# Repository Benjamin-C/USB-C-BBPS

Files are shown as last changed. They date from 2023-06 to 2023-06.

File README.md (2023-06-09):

# USBC-BBPS
A USBC-PD powered breadboard power supply with selectable voltage outputs. This lets you power your project with 3.3V and/or a voltage of your choice provided by a USBC Power Delivery capable power supply.

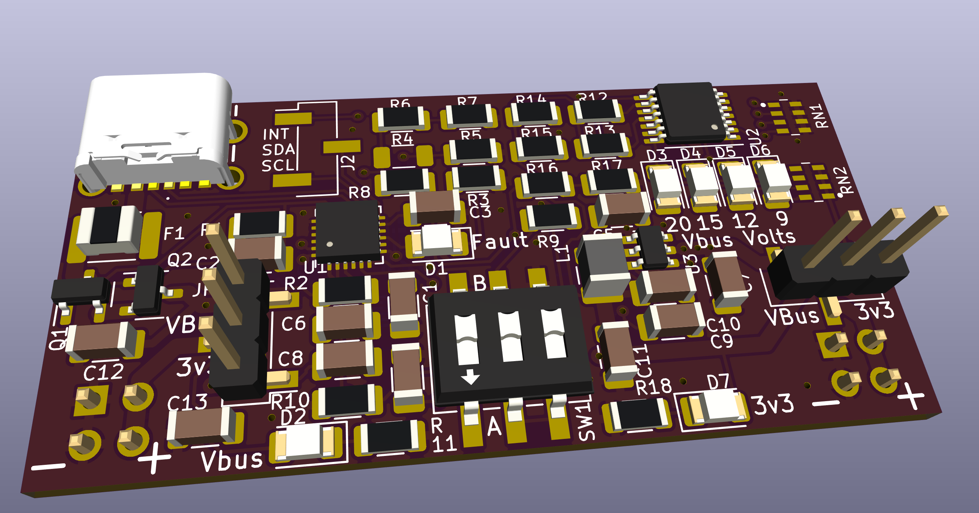
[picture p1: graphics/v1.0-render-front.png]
Front render

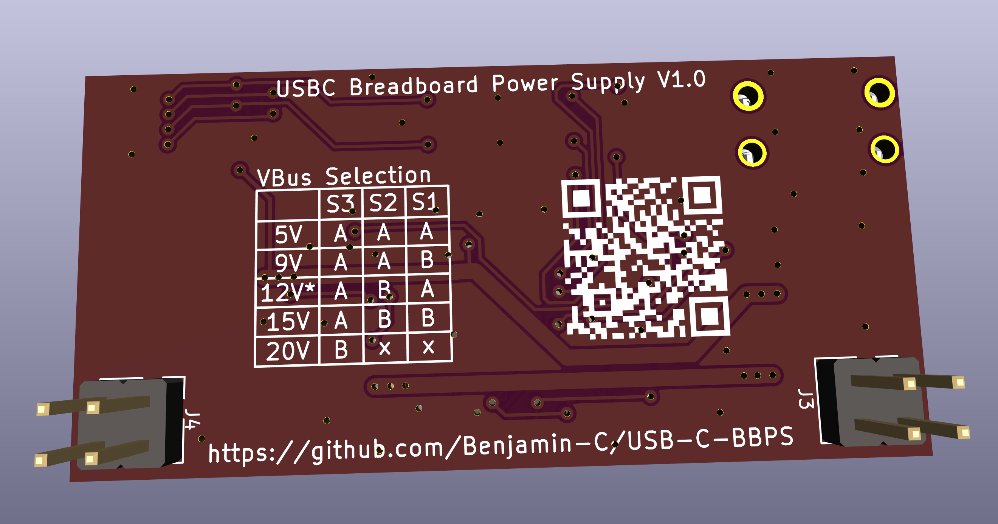
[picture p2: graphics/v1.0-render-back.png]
Front render


## Major Features
* A [CYPD3177-24LQXQT](https://www.infineon.com/cms/en/product/universal-serial-bus/usb-c-charging-port-controllers/ez-pd-barrel-connector-replacement-bcr/cypd3177-24lqxqt/) USBC PD Interface IC to supporting PD3.0 Revision 2.0 Version 1.3
* A [AP63203WU](https://www.mouser.com/ProductDetail/Diodes-Incorporated/AP63203WU-7?qs=u16ybLDytRZ1JqxbuLkMJw%3D%3D) 3.3V switching regulator to always have 3.3V available for microcontrollers
* An [LM339PWRG4](https://www.ti.com/product/LM339/part-details/LM339PWRG4) based voltage monitor
* 2x2 0.1" Pin headers spaced to fit standard solderless breadboards

## Ratings
* VBUS has a 1.5A polyfuse, so no more than 1.5A may be drawn between the VBUS output and 3.3V regulator (noting that the current drawn by the regulator from VBUS will be less than the current drawn on 3.3V).
* Do not feed power back into either 3.3V or VBUS. Doing so may kill the board or possibly the USB power supply
* Each side of the board has a maximum of 1A. This is not regulated on the board, so don't draw more than that.

## Configuration
### VBUS selection:
| | SW3 | SW2 | SW1 |
|---|-----|-----|-----|
| 5V |  A  |  A  |  A  |
| 9V |  A  |  A  |  B  |
| 12V* |  A  |  B  |  A  |
| 15V  |  A  |  B  |  B  |
| 20V  |  B  |  x  |  x  |

\* 12V is an optional part of the USBC-PD spec, so many laptop chargers including most Apple ones do not support 12V.

### Output Voltage Selection
* Use the 3-pin jumpers on each side of the board to select the voltage output to that side of the breadboard.
* Each side can be independently selected to be 3.3V or VBUS.
* Only 1 VBUS voltage may be used at a time, but it may be used on both sides of the board.
* For any voltage over 5V, one or more of the output voltage monitoring LEDs will be lit. The output voltage is the highest value with a lit LED.
* Power will only be provided to the board once USBC-PD negotiations have completed and the desired voltage has been provided.

### Errors
* If the board is not able to negotiate at least the desired voltage from the upstream power supply, the outputs will be turned off and the fault LED will be turned on and power will be cut from the board.
* If the polyfuse is tripped, all lights on the board will turn off. To reset the polyfuse, turn disconnect power from the board, remove the cause of the over current event, and return power to the board.
* If there is a larger over current event, the protection in the USBC power supply may be triggered before the polyfuse reacts. To fix this, disconnect power from the board, remove the source of the nonrecurrent event, then reconnect power to the board.
* If the 3.3V light and voltage monitoring lights are blinking but the VBUS light is on, this is an indication that the 3.3V regulator may be damaged and require replacement.

## Assembly
* Mount the switch so that the switches are "on" when the switch is towards the bottom of the board and "off" when the switch is towards the top of the board. A "A" state is when the switch is down towards the bottom of the board (connected), and a "B" state is when the switch is towards the top of the board (disconnected)
* Be sure to securely solder the mounting tabs on the USBC connector to prevent damage to the board if the cable is pulled.

## More features!
* The 3 pin connector near the USBC connector exposes the I2C lines from the [CYPD3177-24LQXQT](https://www.infineon.com/cms/en/product/universal-serial-bus/usb-c-charging-port-controllers/ez-pd-barrel-connector-replacement-bcr/cypd3177-24lqxqt/) USBC PD Interface IC, and can be connected to a microcontroller for additional features.

## Design notes
This board was designed entirely by me based on the reference schematics for the utilized ICs.

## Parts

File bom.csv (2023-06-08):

USB-C Powered Breadboard Power Supply V1.0
All parts ordered from Mouser
Thu 08 Jun 2023
Component Count: | 56
Item | Qty | Reference(s) | Value | DPN | MPN
1 | 7 | C1, C3, C7, C10, C11, C12, C13 | 10u | 187-CL31A106MBHNNNE | CL31A106MBHNNNE
2 | 5 | C2, C4, C5, C6, C8 | 1u | 187-CL31B105KBHNFNE | CL31B105KBHNFNE
3 | 1 | C9 | 0.1u | 187-CL31B104KBCNNND | CL31B104KBCNNND
4 | 7 | D1, D2, D3, D4, D5, D6, D7 | LED | 710-156120RS75000 | 156120RS75000
5 | 1 | F1 | 2A | 576-1812L150/24MR | 1812L150/24MR
6 | 1 | J1 | USB_C_Receptacle_PowerOnly_6P | 649-10164359-00011LF | 10164359-00011LF
7 | 1 | J2 | DNP | 649-1012938090301ALF | 10129380-903001ALF
8 | 2 | J3, J4 | Conn_02x02 | 649-1012938190403BLF | 10129381-904003BLF
9 | 2 | JP1, JP2 | Jumper_3_Bridged12 | 649-1012938090301ALF | 10129380-903001ALF
10 | 2 | JS1, JS2 | ~ | 855-M7581-05 | M7581-05
11 | 1 | L1 | 4.7u | 652-SRP3212A-4R7M | SRP3212A-4R7M
12 | 2 | Q1, Q2 | Q_PMOS_GSD | 621-DMP3099L-7 | DMP3099L-7
13 | 2 | R1, R17 | 10k | 652-CR1206FX-1002ELF | CR1206-FX-1002ELF
14 | 1 | R2 | 100 | 652-CR1206FX-1000ELF | CR1206-FX-1000ELF
15 | 3 | R3, R7, R18 | 2k2 | 652-CR1206FX-2201ELF | CR1206-FX-2201ELF
16 | 1 | R4 | DNP
17 | 1 | R5 | 0 | 652-CR1206-J/-000ELF | CR1206-J/-000ELF
18 | 3 | R6, R8, R11 | 5k1 | 652-CR1206FX-5101ELF | CR1206FX-5101ELF
19 | 1 | R9 | 3k | 652-CR1206FX-3001ELF | CR1206-FX-3001ELF
20 | 1 | R10 | 1k2 | 652-CR1206FX-1201ELF | CR1206-FX-1201ELF
21 | 1 | R12 | 10.5k | 652-CR1206FX-1052ELF | CR1206FX-1052ELF
22 | 1 | R13 | 49.9k | 652-CR1206FX-4992ELF | CR1206FX-4992ELF
23 | 1 | R14 | 90.9k | 652-CR1206FX-9092ELF | CR1206FX-9092ELF
24 | 1 | R15 | 162k | 652-CR1206FX-1623ELF | CR1206FX-1623ELF
25 | 1 | R16 | 53.6k | 652-CR1206FX-5362ELF | CR1206-FX-5362ELF
26 | 1 | RN1 | 100k | 603-TC164-FR-07100KL | TC164-FR-07100KL
27 | 1 | RN2 | 2k2 | 603-YC164-FR-072K2L | YC164-FR-072K2L
28 | 1 | SW1 | SW_DIP_x03 | 490-DS04254203BK-SMT | DS04-254-2-03BK-SMT
29 | 1 | U1 | CYPD3177 | 727-CYPD3177-24LQXQT | CYPD3177-24LQXQT
30 | 1 | U2 | LM339 | 595-LM339PWRG4 | LM339PWRG4
31 | 1 | U3 | AP63203WU | 621-AP63203WU-7 | AP63203WU-7

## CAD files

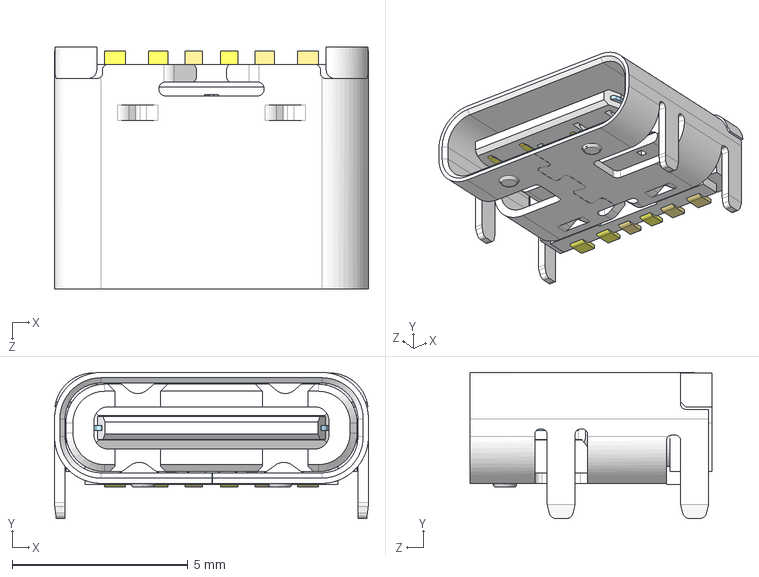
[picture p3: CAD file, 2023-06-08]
3d/J-Amphenol-USB-C.stp
8.94 x 4.16 x 6.90 mm

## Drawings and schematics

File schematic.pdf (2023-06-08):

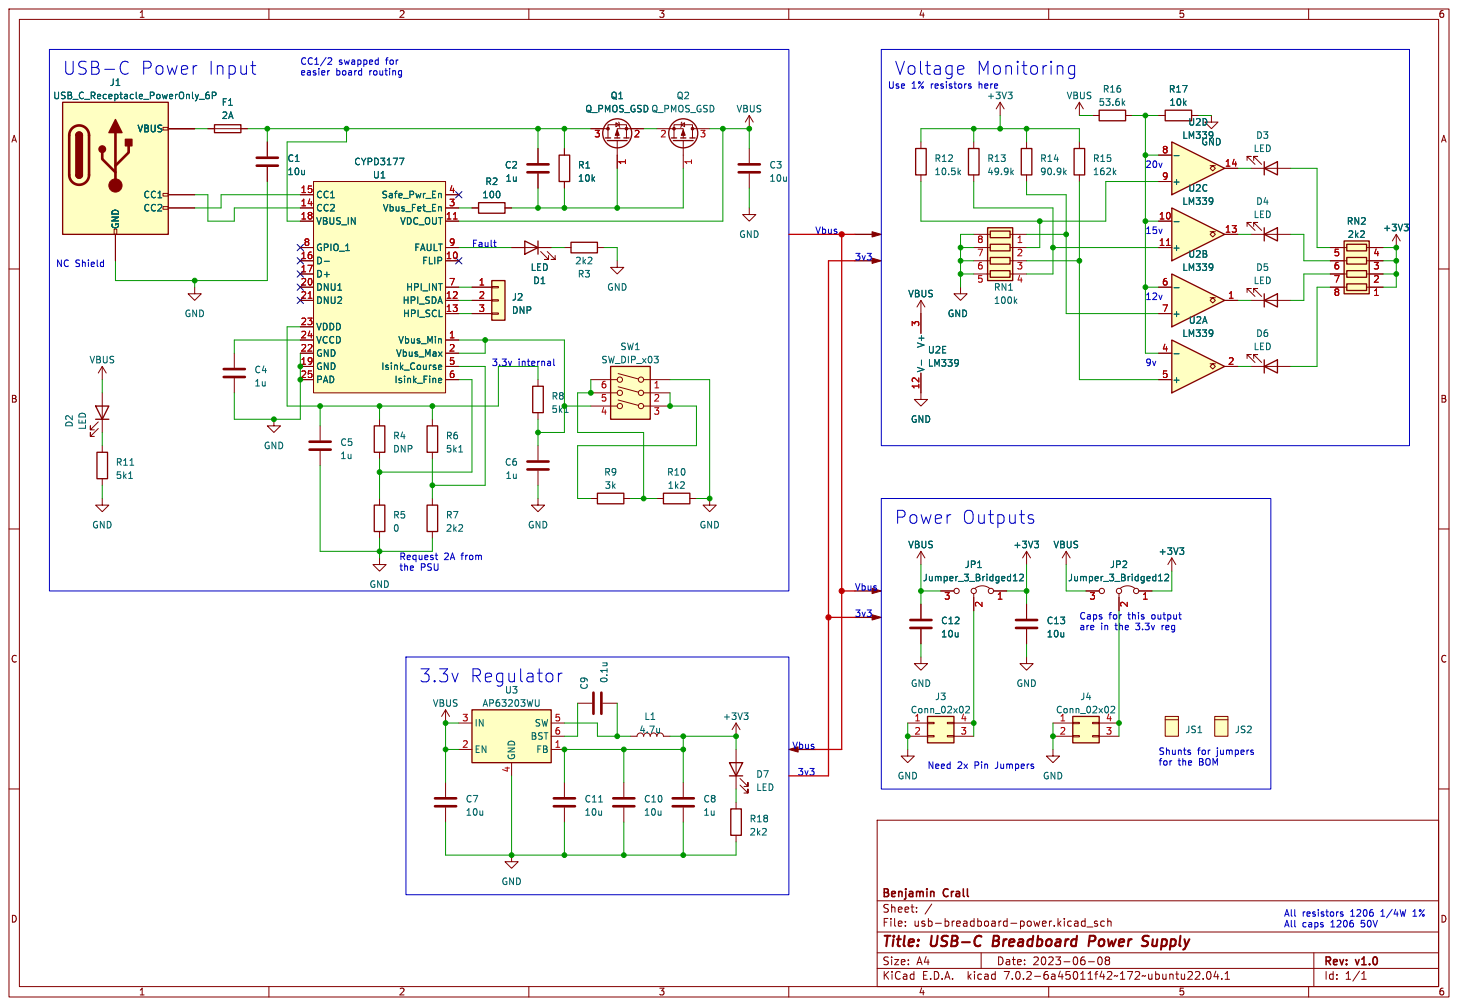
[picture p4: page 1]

All caps 1206 50V Caps for this output are in the 3.3v reg Power Outputs
10u VBUS

File: usb-breadboard-power.kicad_sch Sheet: / Benjamin Crall

Id: 1/1 Title: USB-C Breadboard Power Supply

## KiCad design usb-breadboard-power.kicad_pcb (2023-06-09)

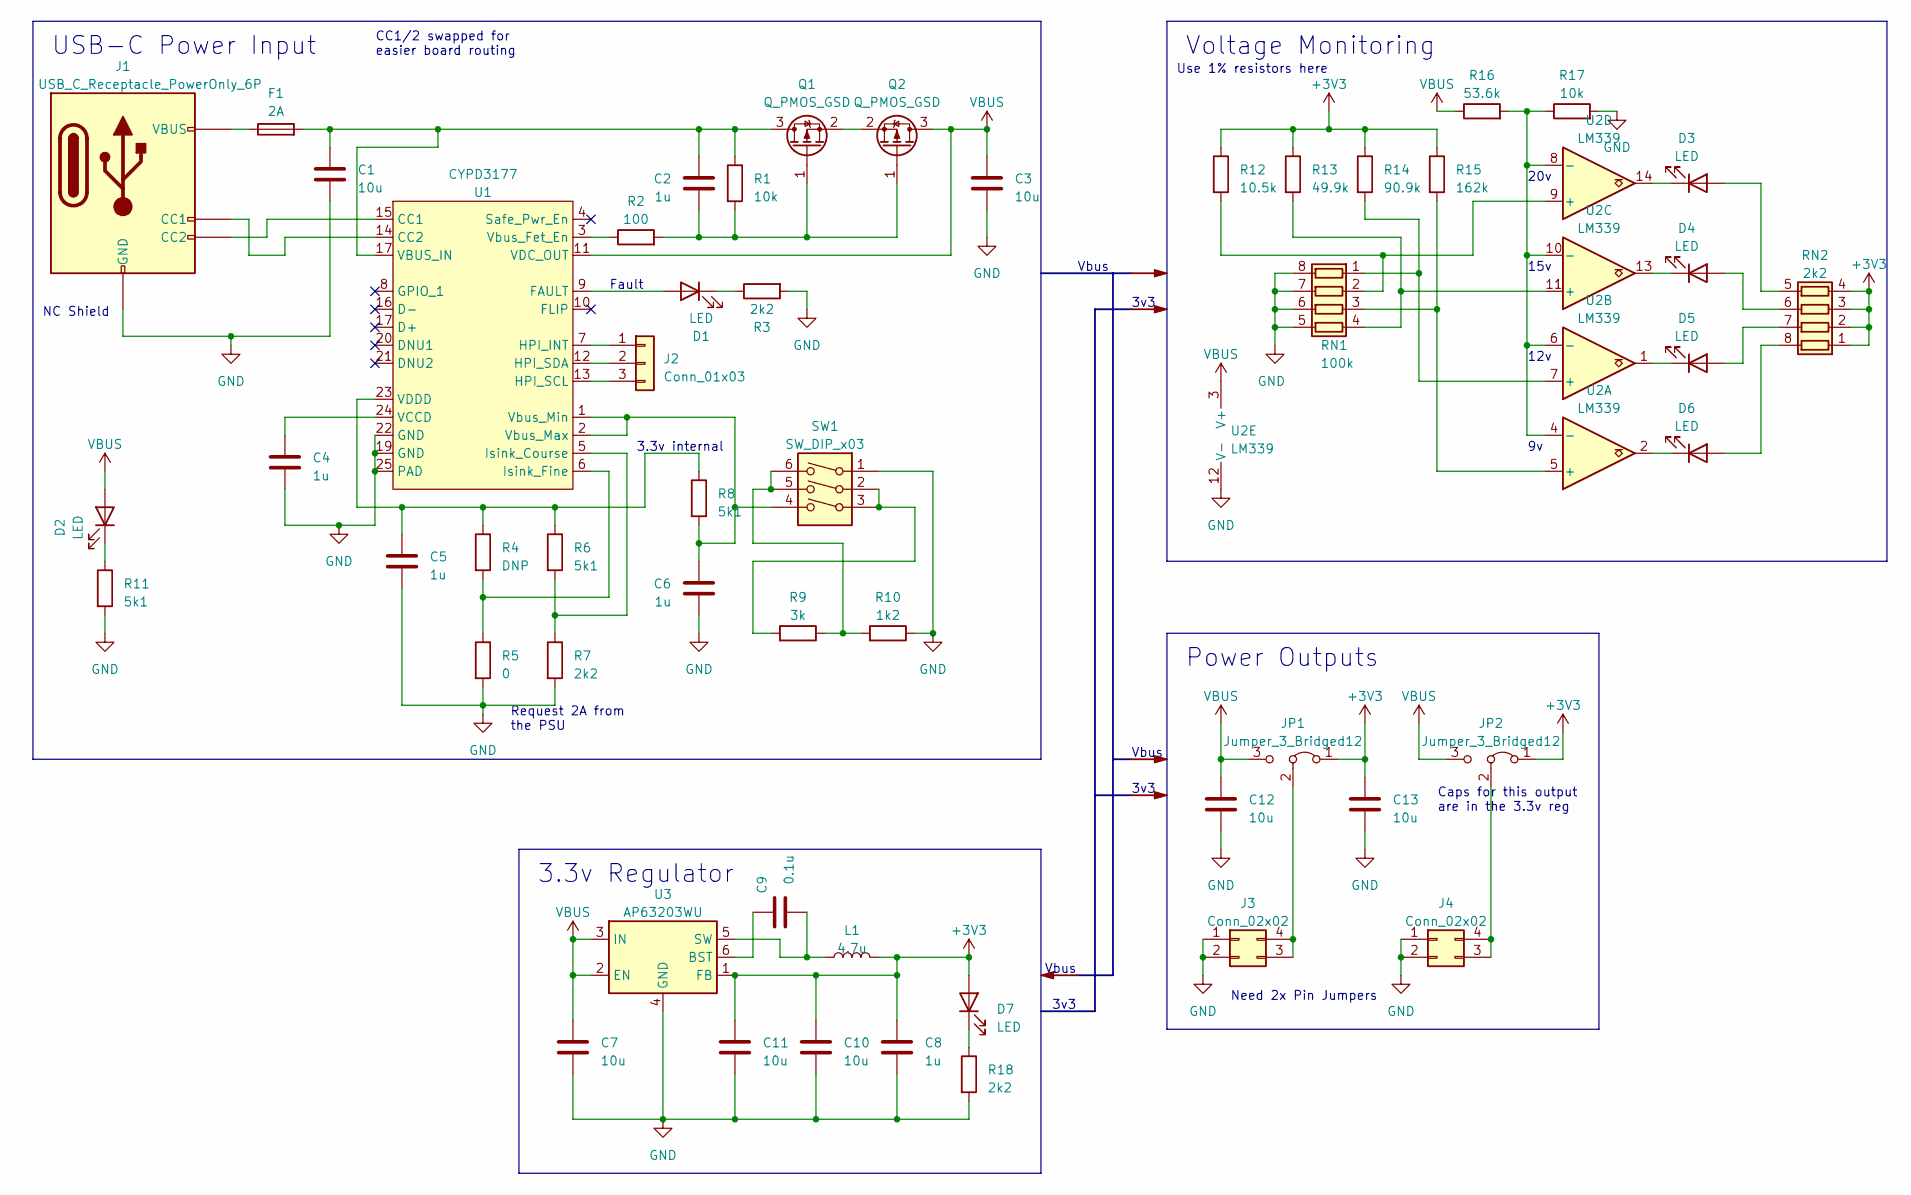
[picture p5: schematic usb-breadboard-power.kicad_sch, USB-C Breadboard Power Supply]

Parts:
C1: 10u; C_1206_3216Metric; MPN CL31A106KAHNNNE
C2, C4, C5, C6, C8: 1u; C_1206_3216Metric; MPN CL31B105KAHNNNE
C3, C7, C10, C11, C12, C13: 10u; C_1206_3216Metric; MPN CL31B105KAHNNNE
C9: 0.1u; C_1206_3216Metric; MPN-m CL31B104KBCNNNC
D1, D2, D3, D4, D5, D6, D7: LED; LED_1206_3216Metric; MPN LTST-C150GKT
F1: 2A; Fuse_1812_4532Metric; MPN-m 1812L150/24MR
J1: USB_C_Receptacle_PowerOnly_6P; J-Amphenol-USB-C; MPN 10164359-00011LF
J2: Conn_01x03; PinHeader_1x03_P2.54mm_Vertical_SMD_Pin1Left; MPN-m 10129380-903001ALF
J3, J4: Conn_02x02; PinHeader_2x02_P2.54mm_Vertical; MPN PH2-04-UA
JP1, JP2: Jumper_3_Bridged12; PinHeader_1x03_P2.54mm_Vertical_SMD_Pin1Left; MPN NREC003SABC-M30RC
L1: 4.7u; L_1210_3225Metric; MPN-m SRP3212A-4R7M
Q1, Q2: Q_PMOS_GSD; SOT-23-3; MPN-m DMP3099L-7
R1: 10k; R_1206_3216Metric; MPN-m CR1206-FX-1002ELF
R2: 100; R_1206_3216Metric; MPN RMCF1206JT100R
R3, R18: 2k2; R_1206_3216Metric; MPN RMCF1206JT2K20
R4: DNP; R_1206_3216Metric
R5: 0; R_1206_3216Metric; MPN-m CR1206-J/-000ELF
R6, R8, R11: 5k1; R_1206_3216Metric; MPN-m CR1206FX-5101ELF
R7: 2k2; R_1206_3216Metric; MPN-m CR1206-FX-2201ELF
R9: 3k; R_1206_3216Metric; MPN-m CR1206-FX-3001ELF
R10: 1k2; R_1206_3216Metric; MPN-m CR1206-FX-1201ELF
R12: 10.5k; R_1206_3216Metric; MPN RMCF1206ZT0R00
R13: 49.9k; R_1206_3216Metric; MPN RMCF1206FT36K5
R14: 90.9k; R_1206_3216Metric; MPN RMCF1206FT73K2
R15: 162k; R_1206_3216Metric; MPN RMCF1206FT137K
R16: 53.6k; R_1206_3216Metric; MPN RMCF1206FT536K
R17: 10k; R_1206_3216Metric; MPN RMCF1206FT100K
RN1: 100k; R_Array_Convex_4x1206; MPN TC164-FR-07100KL
RN2: 2k2; R_Array_Convex_4x1206; MPN TC164-FR-072K2L
SW1: SW_DIP_x03; SW_DIP_SPSTx03_Slide_6.7x9.18mm_W8.61mm_P2.54mm_LowProfile; MPN-m DS04-254-2-03BK-SMT
U1: CYPD3177; QFN-24-1EP_4x4mm_P0.5mm_EP2.8x2.8mm; MPN CYPD3177-24LQXQT
U2: LM339; TSSOP-14_4.4x5mm_P0.65mm; MPN LM339PWRG3
U3: AP63203WU; TSOT-23-6; MPN-m AP63203WU-7

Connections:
+3V3: C8.1, C10.1, C11.1, C13.1, D7.2 (A), JP1.1 (A), JP2.1 (A), L1.2, R12.1, R13.1, R14.1, R15.1, RN2.1 (R1.1), RN2.2 (R2.1), RN2.3 (R3.1), RN2.4 (R4.1), U3.1 (FB)
GND: C1.2, C3.2, C4.2, C5.2, C6.2, C7.2, C8.2, C10.2, C11.2, C12.2, C13.2, J1.A12 (GND), J1.B12 (GND), J3.1, J3.2, J4.1, J4.2, R3.2, R5.2, R7.2, R10.1, R11.2, R17.2, R18.2, RN1.5 (R4.2), RN1.6 (R3.2), RN1.7 (R2.2), RN1.8 (R1.2), SW1.1, U1.19 (GND), U1.22 (GND), U1.25 (PAD), U2.12 (V-), U3.4 (GND)
unnamed: D1.2 (A), U1.9 (FAULT)
unnamed: D1.1 (K), R3.1
unnamed: D2.1 (K), R11.1
unnamed: D3.2 (A), RN2.5 (R4.2)
unnamed: D3.1 (K), U2.14
unnamed: D4.2 (A), RN2.6 (R3.2)
unnamed: D4.1 (K), U2.13
unnamed: D5.2 (A), RN2.7 (R2.2)
unnamed: D5.1 (K), U2.1
unnamed: D6.2 (A), RN2.8 (R1.2)
unnamed: D6.1 (K), U2.2
unnamed: D7.1 (K), R18.1
unnamed: F1.1, J1.A9 (VBUS), J1.B9 (VBUS)
unnamed: J1.A5 (CC1), U1.14 (CC2)
unnamed: J1.B5 (CC2), U1.15 (CC1)
unnamed: J2.1, U1.7 (HPI_INT)
unnamed: J2.2, U1.12 (HPI_SDA)
unnamed: J2.3, U1.13 (HPI_SCL)
unnamed: J3.3, J3.4, JP1.2 (C)
unnamed: J4.3, J4.4, JP2.2 (C)
unnamed: C1.1, C2.1, F1.2, Q1.3 (D), R1.1, U1.17 (D+), U1.18 (VBUS_IN)
unnamed: C2.2, Q1.1 (G), Q2.1 (G), R1.2, R2.2
unnamed: Q1.2 (S), Q2.2 (S)
unnamed: R9.2, SW1.2, SW1.3
unnamed: R9.1, R10.2, SW1.5, SW1.6
unnamed: R14.2, RN1.1 (R1.1), U2.7 (+)
unnamed: R12.2, RN1.2 (R2.1), U2.9 (+)
unnamed: R15.2, RN1.3 (R3.1), U2.5 (+)
unnamed: R13.2, RN1.4 (R4.1), U2.11 (+)
unnamed: R6.2, R7.1, U1.5 (Isink_Course)
unnamed: R4.2, R5.1, U1.6 (Isink_Fine)
unnamed: C4.1, U1.24 (VCCD)
unnamed: C5.1, R4.1, R6.1, R8.1, U1.23 (VDDD)
unnamed: R2.1, U1.3 (Vbus_Fet_En)
unnamed: C6.1, R8.2, SW1.4, U1.1 (Vbus_Min), U1.2 (Vbus_Max)
unnamed: R16.2, R17.1, U2.4 (-), U2.6 (-), U2.8 (-), U2.10 (-)
unnamed: C9.2, U3.6 (BST)
unnamed: C9.1, L1.1, U3.5 (SW)
VBUS: C3.1, C7.1, C12.1, D2.2 (A), JP1.3 (B), JP2.3 (B), Q2.3 (D), R16.1, U1.11 (VDC_OUT), U2.3 (V+), U3.2 (EN), U3.3 (IN)

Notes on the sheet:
Power Outputs
3v3
Use 1% resistors here
12v
USB-C Power Input
NC Shield
3.3v internal
Request 2A from the PSU
Vbus
15v
CC1/2 swapped for easier board routing
Voltage Monitoring
20v
Caps for this output are in the 3.3v reg
Need 2x Pin Jumpers
3.3v Regulator
Fault

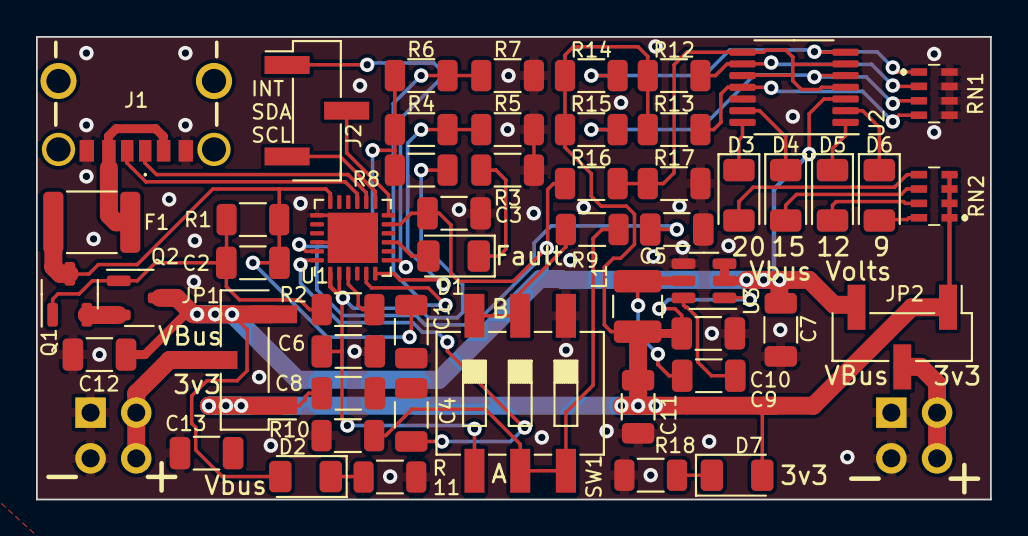
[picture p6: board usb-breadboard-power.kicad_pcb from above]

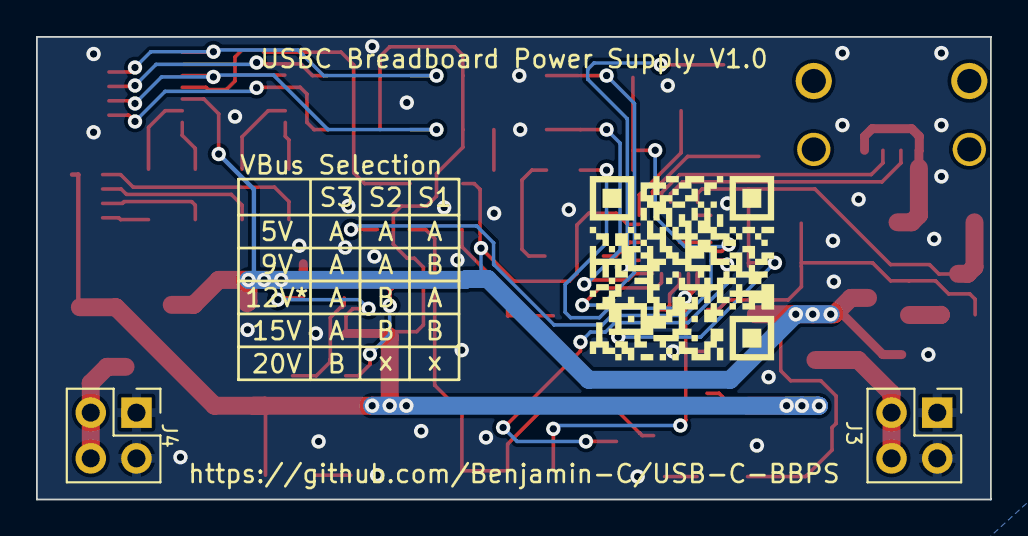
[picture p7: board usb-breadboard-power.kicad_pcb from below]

Board: 2 copper layers, 53.0 x 25.7 mm, 54 parts (2 on the bottom side), 41 nets.

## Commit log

2023-06-08 Swapped IC to one that supports 12v
    [usb-breadboard-power.kicad_pcb, usb-breadboard-power.kicad_sch]
2023-06-08 Cleaned up schematic and added Vbus LED
    [usb-breadboard-power.kicad_pcb, usb-breadboard-power.kicad_sch]
2023-06-08 Updated Mouser BOM
    [usb-breadboard-power.kicad_pcb, usb-breadboard-power.kicad_sch]
2023-06-08 Fixed BOM errors
    [usb-breadboard-power.kicad_sch]
2023-06-08 Updated gitignore and added fuse
    [J-Amphenol-USB-C.stp, usb-breadboard-power.kicad_pcb, usb-breadboard-power.kicad_sch]
2023-06-08 More small fixes
    [notes.ods, usb-breadboard-power.kicad_sch]
2023-06-08 Moved voltage LED refdes out from under diodes
    [usb-breadboard-power.kicad_pcb]
2023-06-08 Fixed switching reg layout
    [usb-breadboard-power.kicad_pcb, usb-breadboard-power.kicad_sch]
2023-06-08 Confirmed BOM
    [usb-breadboard-power.kicad_pcb, usb-breadboard-power.kicad_sch]
2023-06-08 Added jumper shunts to BOM
    [usb-breadboard-power.kicad_sch]
2023-06-08 Fixed issues discovered while building first run
    [usb-breadboard-power.kicad_pcb, usb-breadboard-power.kicad_sch]
2023-06-08 Cleaned up repo
    [bom.csv, notes.ods, usb-breadboard-power.kicad_pcb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]
2023-06-08 Updated documentation
    [usb-breadboard-power.kicad_pcb]
2023-06-08 Added board fab files
    [usb-breadboard-power-B_Cu.gbr, usb-breadboard-power-B_Mask.gbr, usb-breadboard-power-B_Paste.gbr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]
2023-06-08 created VBUS selection guide
    made an SVG of the table showing how to select vbus voltage and added it to the "graphics" folder
2023-06-09 Added info to back of board
    [usb-breadboard-power-B_Cu.gbr, usb-breadboard-power-B_Mask.gbr, usb-breadboard-power-B_Paste.gbr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]
